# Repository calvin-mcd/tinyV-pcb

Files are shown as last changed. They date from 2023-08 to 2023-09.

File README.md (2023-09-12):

# tinyV-pcb

This is an integrated, hotswap pcb for the tinyV by BA (BAonDiscord7634). It is designed to be snapped in half at the mousebites in the middle of the pcb. a single 9pin jst cable will then connect the two halves.

## Layout

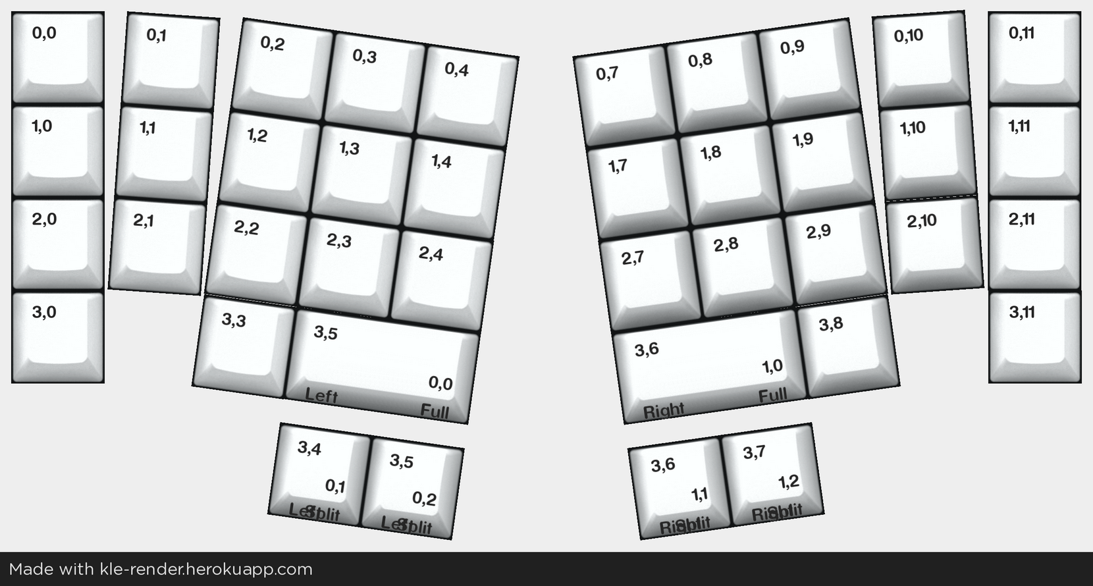
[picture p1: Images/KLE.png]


[Link](http://www.keyboard-layout-editor.com/#/gists/8b90b401f7d69f0f0c08135f7b12a323)

## Pictures

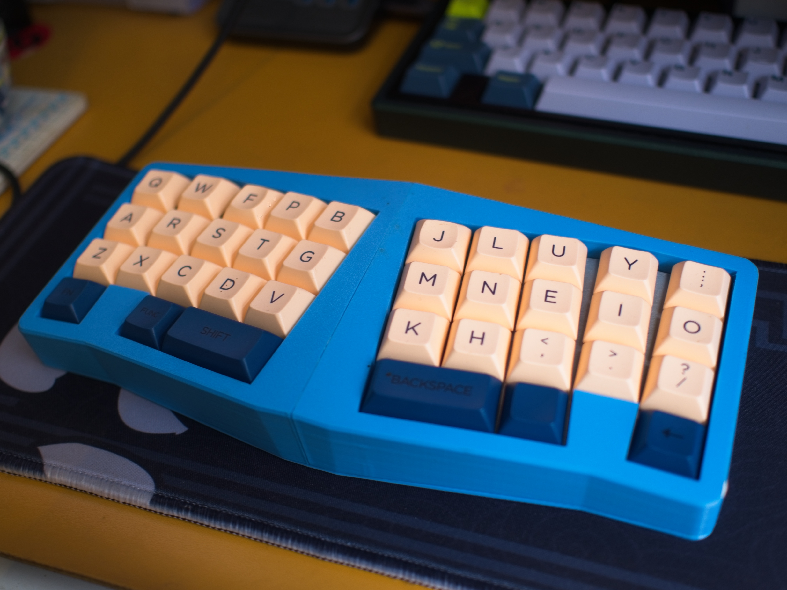
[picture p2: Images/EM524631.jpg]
  
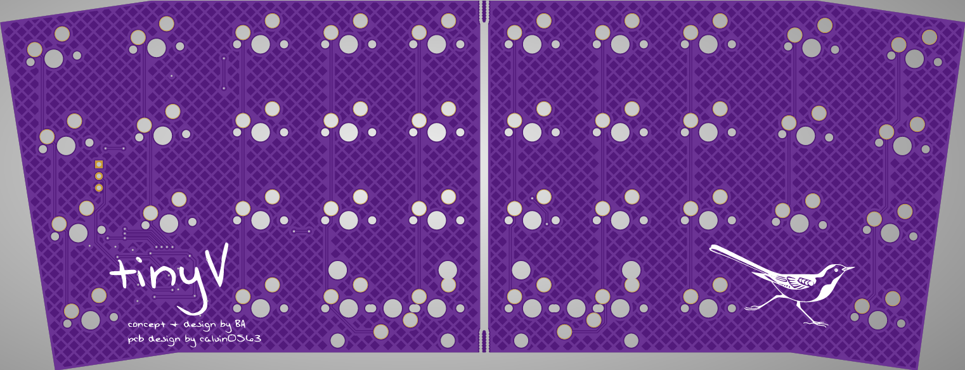
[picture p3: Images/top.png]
  
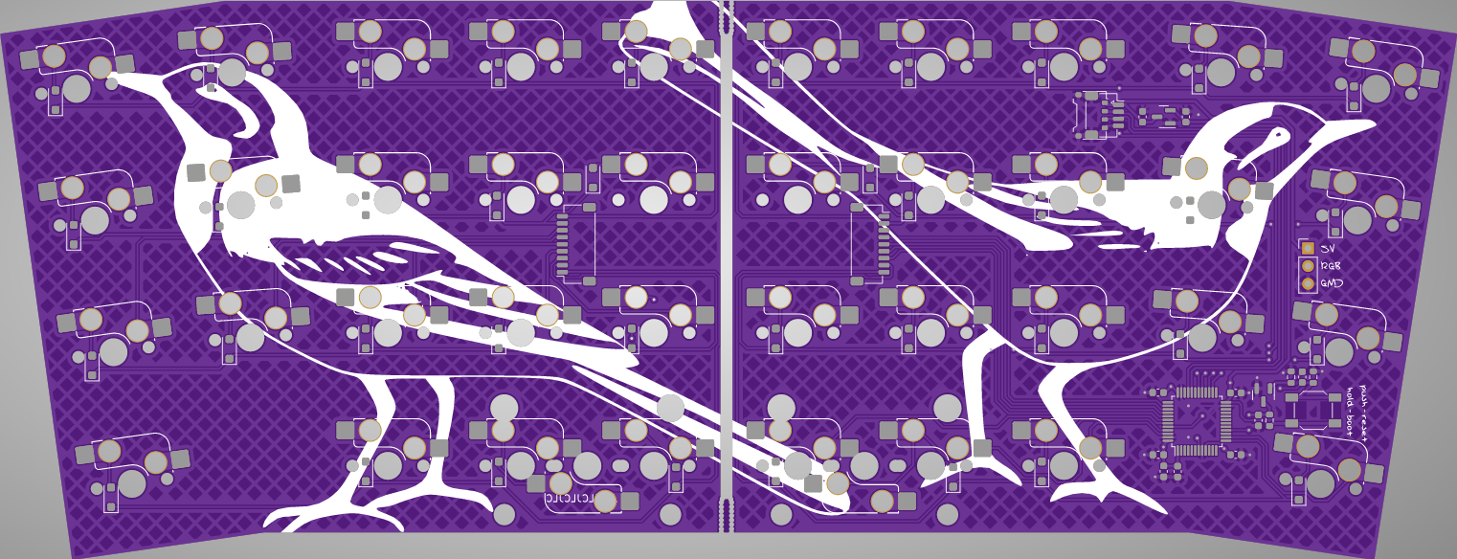
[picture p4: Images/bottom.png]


## Case

The case is being created by BA.

early design examples:

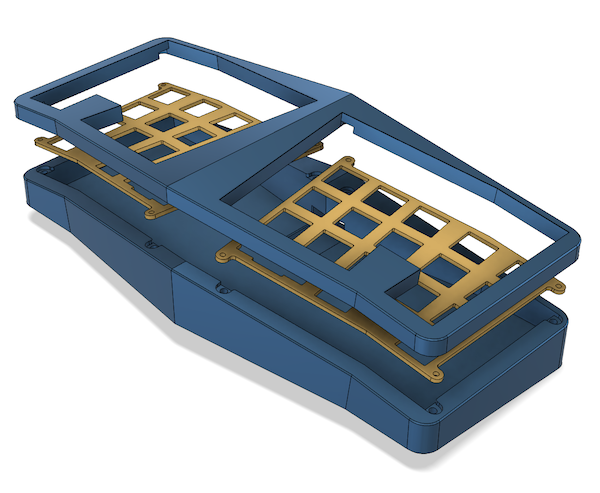
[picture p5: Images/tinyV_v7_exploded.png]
  
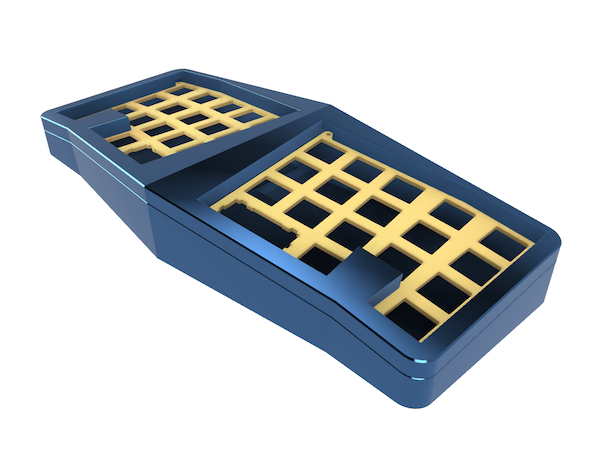
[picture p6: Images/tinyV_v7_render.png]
  
  
## Todo

- [ ] order & test pcb
- [ ] create firmware
- [ ] order & test case prototype

## Disclaimer

This PCB has been fully tested and confirmed to work. The members of the PCB development team are however not liable if you end up with a non-functional pcb. Order at your own risk. Support will not be provided but pull requests will be reviewed and possibly accepted.

## License

Shield: 

This work is licensed under a  
[Creative Commons Attribution-NonCommercial-ShareAlike 4.0 International License](http://creativecommons.org/licenses/by-nc-sa/4.0/).



## Credits

Any questions, contact BAonDiscord7634 & Calvin0563 on Discord.

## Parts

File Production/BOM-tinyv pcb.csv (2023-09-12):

Comment | Designator | Footprint | LCSC
1uF | C1,C2,C8 | C_0603_1608Metric | C106215
Conn_01x09_Socket | J5,J6 | JST_SH_SM09B-SRSS-TB_1x09-1MP_P1.00mm_Horizontal | C160408
100nF | C10,C3,C4,C5,C9 | C_0603_1608Metric | C2930551
RST | SW1 | SW_SPST_SKQG_WithoutStem | C318884
MCP1700x-330xxTT | U2 | SOT-23 | C39051
100k | R3 | R_0603_1608Metric | C4107493
MX_SW_HS | MX1,MX10,MX11,MX12,MX13,MX14,MX15,MX16,MX17,MX18,MX19,MX2,MX20,MX21,MX22,MX23,MX24,MX25,MX26,MX27,MX28,MX29,MX3,MX30,MX31,MX32,MX33,MX34,MX35,MX36,MX37,MX38,MX39,MX4,MX40,MX5,MX6,MX7,MX8,MX9 | SW_MX_HS_1u | C5156480
Pico EZmate | J2 | Molex_Pico-EZmate_78171-0004_1x04-1MP_P1.20mm_Vertical | C588524
10uF | C11 | C_0603_1608Metric | C596327
D_Small | D1,D10,D11,D12,D13,D14,D15,D16,D17,D18,D19,D2,D20,D21,D22,D23,D24,D25,D26,D27,D28,D29,D3,D30,D31,D33,D34,D35,D36,D37,D38,D4,D40,D5,D6,D7,D8,D9 | D_SOD-123F | C64898
4.7uF | C7 | C_0603_1608Metric | C695178
STM32F072C8Tx | U1 | LQFP-48_7x7mm_P0.5mm | C80488
2N7002 | Q1 | SOT-23 | C8545
10k | R1,R2 | R_0603_1608Metric | C859115

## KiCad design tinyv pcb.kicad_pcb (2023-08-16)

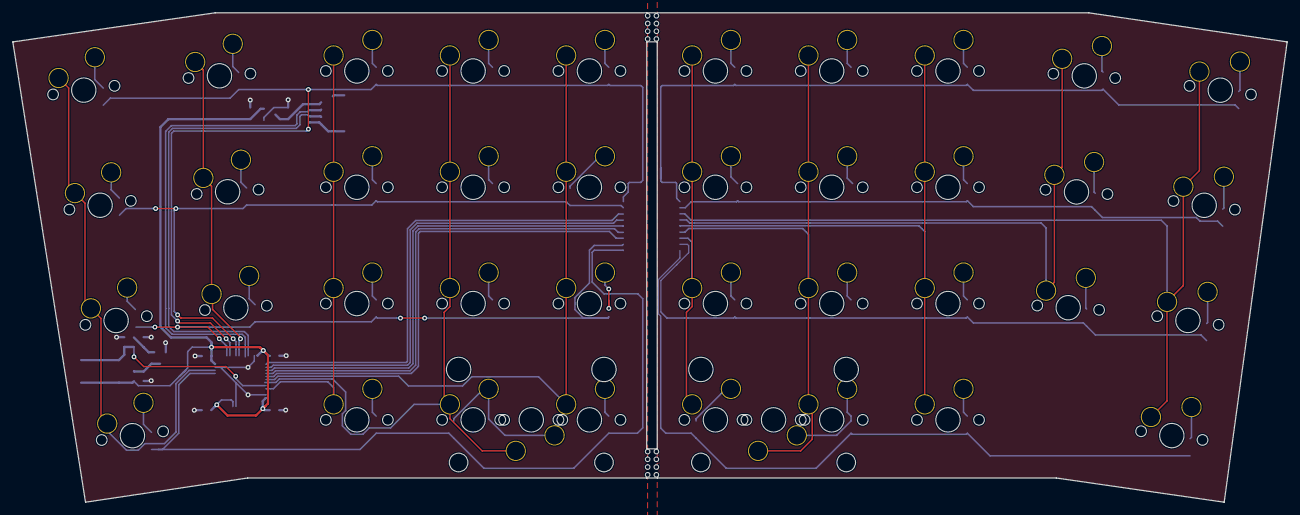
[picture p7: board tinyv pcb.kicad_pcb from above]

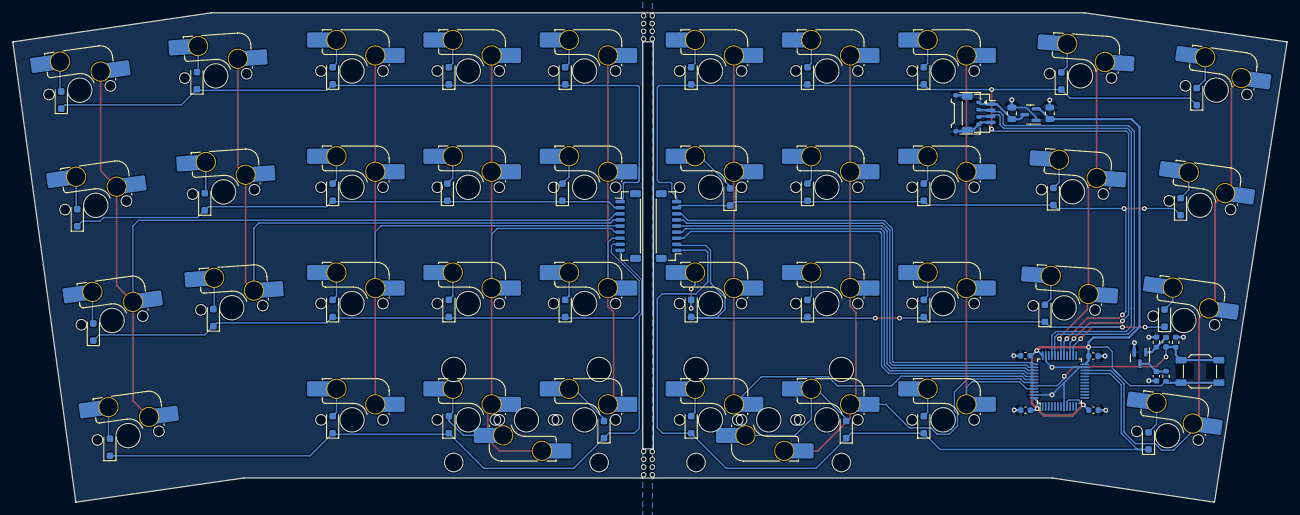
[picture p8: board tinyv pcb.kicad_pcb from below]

Board: 2 copper layers, 208.8 x 80.2 mm, 99 parts (97 on the bottom side), 60 nets.

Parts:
C1, C2: 1uF; C_0805_2012Metric
C3, C4, C5, C6: 100nF; C_0603_1608Metric
C7: 4.7u; C_0603_1608Metric
C8: 1u; C_0603_1608Metric
D1, D2, D3, D4, D5, D6, D7, D8, D9, D10, D11, D12, D13, D14, D15, D16, D17, D18, D19, D20, D21, D22, D23, D24, D25, D26, D27, D28, D29, D30, D31, D33, D34, D35, D36, D37, D38, D40: D_Small; D_SOD-123F
J1: JST SH; JST_SH_SM04B-SRSS-TB_1x04-1MP_P1.00mm_Horizontal
J2: Pico EZmate; Molex_Pico-EZmate_78171-0004_1x04-1MP_P1.20mm_Vertical
J5, J6: Conn_01x09_Socket; JST_SH_BM09B-SRSS-TB_1x09-1MP_P1.00mm_Vertical
MX1, MX2, MX3, MX4, MX5, MX6, MX7, MX8, MX9, MX10, MX11, MX12, MX13, MX14, MX15, MX16, MX17, MX18, MX19, MX20, MX21, MX22, MX23, MX24, MX25, MX26, MX27, MX28, MX29, MX30, MX31, MX32, MX33, MX34, MX35, MX36, MX37, MX38, MX39, MX40: MX_SW_HS; SW_MX_HS_1u
Q1: 2N7002; SOT-23
R1, R2: 10k; R_0603_1608Metric
R3: 100k; R_0603_1608Metric
S1, S2: MX_stab; STAB_MX_2u
SW1: RST; SW_SPST_SKQG_WithoutStem
U1: STM32F072C8Tx; LQFP-48_7x7mm_P0.5mm
U2: MCP1700x-330xxTT; SOT-23

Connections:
+3V3: C2.1, C3.1, C4.1, C5.1, C6.1, R1.1, SW1.2, U1.9 (VDDA), U1.24 (VDD), U1.36 (VDDIO2), U1.48 (VDD), U2.2 (VO)
+5V: C1.1, J1.1, J2.1, U2.3 (VI)
BOOT0: C7.1, R2.1, SW1.1, U1.44 (BOOT0)
COL0: MX1.1, MX11.1, MX21.1, MX31.1, U1.22 (PB11)
COL1: MX2.1, MX12.1, MX22.1, U1.30 (PA9)
COL2: MX3.1, MX13.1, MX23.1, MX33.1, U1.45 (PB8)
COL3: MX4.1, MX14.1, MX24.1, MX32.2, MX34.1, U1.43 (PB7)
COL4: MX5.1, MX15.1, MX25.1, MX35.1, U1.42 (PB6)
COL5: J5.3, J6.7, MX6.1, MX16.1, MX26.1, MX36.1, U1.41 (PB5)
COL6: J5.4, J6.6, MX7.1, MX17.1, MX27.1, MX37.1, MX39.2, U1.40 (PB4)
COL7: J5.5, J6.5, MX8.1, MX18.1, MX28.1, MX38.1, U1.39 (PB3)
COL8: J5.6, J6.4, MX9.1, MX19.1, MX29.1, U1.38 (PA15)
COL9: J5.7, J6.3, MX10.1, MX20.1, MX30.1, MX40.1, U1.37 (PA14)
D_N: J1.2, J2.2, U1.32 (PA11)
D_P: J1.3, J2.3, U1.33 (PA12)
GND: C1.2, C2.2, C3.2, C4.2, C5.2, C6.2, C8.1, J1.4, J1.MP (MountPin), J2.4, J2.MP (MountPin), Q1.2 (S), R2.2, R3.2, U1.8 (VSSA), U1.23 (VSS), U1.35 (VSS), U1.47 (VSS), U2.1 (GND)
NRST: C8.2, Q1.3 (D), R1.2
unnamed: D1.2 (A), MX1.2
unnamed: D2.2 (A), MX2.2
unnamed: D3.2 (A), MX3.2
unnamed: D4.2 (A), MX4.2
unnamed: D5.2 (A), MX5.2
unnamed: D6.2 (A), MX6.2
unnamed: D7.2 (A), MX7.2
unnamed: D8.2 (A), MX8.2
unnamed: D9.2 (A), MX9.2
unnamed: D10.2 (A), MX10.2
unnamed: D11.2 (A), MX11.2
unnamed: D12.2 (A), MX12.2
unnamed: D13.2 (A), MX13.2
unnamed: D14.2 (A), MX14.2
unnamed: D15.2 (A), MX15.2
unnamed: D16.2 (A), MX16.2
unnamed: D17.2 (A), MX17.2
unnamed: D18.2 (A), MX18.2
unnamed: D19.2 (A), MX19.2
unnamed: D20.2 (A), MX20.2
unnamed: D21.2 (A), MX21.2
unnamed: D22.2 (A), MX22.2
unnamed: D23.2 (A), MX23.2
unnamed: D24.2 (A), MX24.2
unnamed: D25.2 (A), MX25.2
unnamed: D26.2 (A), MX26.2
unnamed: D27.2 (A), MX27.2
unnamed: D28.2 (A), MX28.2
unnamed: D29.2 (A), MX29.2
unnamed: D30.2 (A), MX30.2
unnamed: D31.2 (A), MX31.2
unnamed: D33.2 (A), MX33.2
unnamed: D34.2 (A), MX32.1, MX34.2
unnamed: D35.2 (A), MX35.2
unnamed: D36.2 (A), MX36.2
unnamed: D37.2 (A), MX37.2, MX39.1
unnamed: D38.2 (A), MX38.2
unnamed: D40.2 (A), MX40.2
unnamed: C7.2, Q1.1 (G), R3.1
ROW0: D1.1 (K), D2.1 (K), D3.1 (K), D4.1 (K), D5.1 (K), D6.1 (K), D7.1 (K), D8.1 (K), D9.1 (K), D10.1 (K), J5.9, J6.1, U1.27 (PB14)
ROW1: D11.1 (K), D12.1 (K), D13.1 (K), D14.1 (K), D15.1 (K), D16.1 (K), D17.1 (K), D18.1 (K), D19.1 (K), D20.1 (K), J5.8, J6.2, U1.29 (PA8)
ROW2: D21.1 (K), D22.1 (K), D23.1 (K), D24.1 (K), D25.1 (K), D26.1 (K), D27.1 (K), D28.1 (K), D29.1 (K), D30.1 (K), J5.2, J6.8, U1.26 (PB13)
ROW3: D31.1 (K), D33.1 (K), D34.1 (K), D35.1 (K), D36.1 (K), D37.1 (K), D38.1 (K), D40.1 (K), J5.1, J6.9, U1.21 (PB10)

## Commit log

2023-08-16 routing improvements, error check, cleanup
    [tinyv pcb.kicad_pcb, tinyv pcb.kicad_sch]
2023-08-20 production files & bom, pos missing
    [tinyv pcb-B_Cu.gbr, tinyv pcb-B_Mask.gbr, tinyv pcb-B_Paste.gbr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]
2023-08-24 slight routing change, necessary?
    [tinyv pcb.kicad_sch]
2023-08-29 production files created
    not yet finished
    [BOM-tinyv pcb.csv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]
2023-12-16 added a version that uses FFC instead of JST
    [tinyv pcb FFC.kicad_sch, tinyv pcb.kicad_sch]
2024-02-23 fresh gerbers
    [tinyv pcb FFC-B_Cu.gbr, tinyv pcb FFC-B_Mask.gbr, tinyv pcb FFC-B_Paste.gbr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]
